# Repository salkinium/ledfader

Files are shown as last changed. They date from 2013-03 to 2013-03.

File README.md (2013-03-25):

Standalone driver for 32 LEDs
=============================

This board should drive 32 LEDs using 12bit resolution at a ~2kHz frequency
using two TLC5940s controlled by a ATmega328.
There is one button and a vibration sensor, to changes modes and save power (both optional).
The serial can be accessed (so Arduino support should be possible).

The software is written using the [XPCC library][xpcc], for its TLC5940 driver,
gamma correction and workflow classes.

Organisation
------------

This repository is organized as follows:

-	The *hardware* folder contains the EAGLE schematics and layouts of the
	electronic assembly, with parts list and datasheets.
- 	The *software* folder contains the software for the microcontroller.

[xpcc]: http://xpcc.kreatives-chaos.com

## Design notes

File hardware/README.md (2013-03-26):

LED driver hardware
===================

The ATmega328P can fade 32 LEDs using two TLC5940 12bit LED drivers.

Programmer
----------

The ATmega is programmed using the standard ISP interface, however to save space,
a smaller footprint is used.
On standard PCBs with 1.6mm thickness, the board fits exacly between to RM 2.00 pins,
so I just use a 2x3 RM 2.00 pin header to attach my programmer to it from the side.
This takes up a *lot* less space and the connection is secure enough.

Parts List and Description
--------------------------

### Battery charger

Using [Sparkfuns USB Lipo charger](
https://www.sparkfun.com/products/10401).

### Battery

This circuit can be powered by a standard 3.7V LiPo/LiIon rechargeable battery **without** voltage regulator.

### Microcontroller

A ATmega328P in a 32-pin TQFP package is used.

### Resonator

Small footprint, reasonable frequency stability of ±0.5% at 8MHz: CSTCE 8,00.

Some background on the maximum possible frequency:
The 3.7V LiPo battery voltage can be anywhere between 3V to 4.2V.

The ATmega328P is rated at 10Mhz @ 2.7V and 20Mhz @ 4.5V.
For 3V the maximum frequency is already above 10MHz, so we're fine.  

The lowest voltage for 8MHz is:  
(8MHz - 4MHz) * (2.7 - 1.8)V / (10 - 4)MHz + 1.8V = 2.4V

But the TLC5940 requires 3V minimum voltage, so never mind.

### Tactile Switch

A light touch switch from Panasonic is used:  
EVQPS with J-bend terminals: EVQPSG02K without Boss

### Vibration sensor

MVS 0608.02 is used.  
It's not widely available so you can leave it out.

### Other parts

Some 0603 and 0805 resistors and capacitors are used.

A RM 2.00 mm In-System Programming socket is used.

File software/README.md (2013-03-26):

LED drivers software
====================

The software is an example which manages all the LEDs on my bike helmet.
There is also some more advances stuff in there like sleep modes, which I use to minimize power use when the helmet is not in use.

You can/should adapt the firmware to your needs.
If you do not want to use XPCC, you should also be able to flash an Arduino bootloader on there (fingers crossed).

Firmware
--------

The sources are compiled using the [XPCC library][xpcc], which is used for
GPIO, TLC5940 Drivers, Processing, Build System and Serial Debugging.  
Enter the `source` directory

	$ cd /path/to/ledfader/software/source

To compile, execute:

	$ scons

The fuses are set at 0xad (low), 0xd9 (high), 0x07 (extended).  
To set the fuses on the microcontroller, execute:

	$ scons fuse

You can also set the fuses manually using this command:

	$ avrdude -p atmega328p -c avrispmkii -P usb -u \
	-U lfuse:w:0xad:m -U hfuse:w:0xd9:m -U efuse:w:0x07:m

To flash the binary onto the microcontroller, execute:

	$ scons program

Installing XPCC
---------------

XPCC is provided as a git submodule, to use it run this in the root `ledfader/`
directory:

	$ git submodule init
	$ git submodule update

To install the XPCC build system on OS X (tested on Lion/Mountain Lion):

1.	Install [Homebrew][]:  
	`$ ruby -e "$(curl -fsSL https://raw.github.com/mxcl/homebrew/go)"`
2.	Install some dependencies (requires Python 2.x):  
	`$ brew install scons python`  
	`$ pip install lxml jinja2`
3.	Install the latest precompiled version of [avr-gcc from ObDev][obdev].

To install the XPCC build system on Linux (tested on Ubuntu 12.04):

	$ sudo apt-get update
	$ sudo apt-get install python scons python-jinja2 python-lxml \
	gcc-avr binutils-avr avr-libc avrdude

More information on installing the XPCC build system can be [found here][xpcc-install].

[xpcc]: http://xpcc.kreatives-chaos.com/
[homebrew]: http://mxcl.github.com/homebrew/
[obdev]: http://www.obdev.at/products/crosspack/download.html
[xpcc-install]: http://xpcc.kreatives-chaos.com/install.html

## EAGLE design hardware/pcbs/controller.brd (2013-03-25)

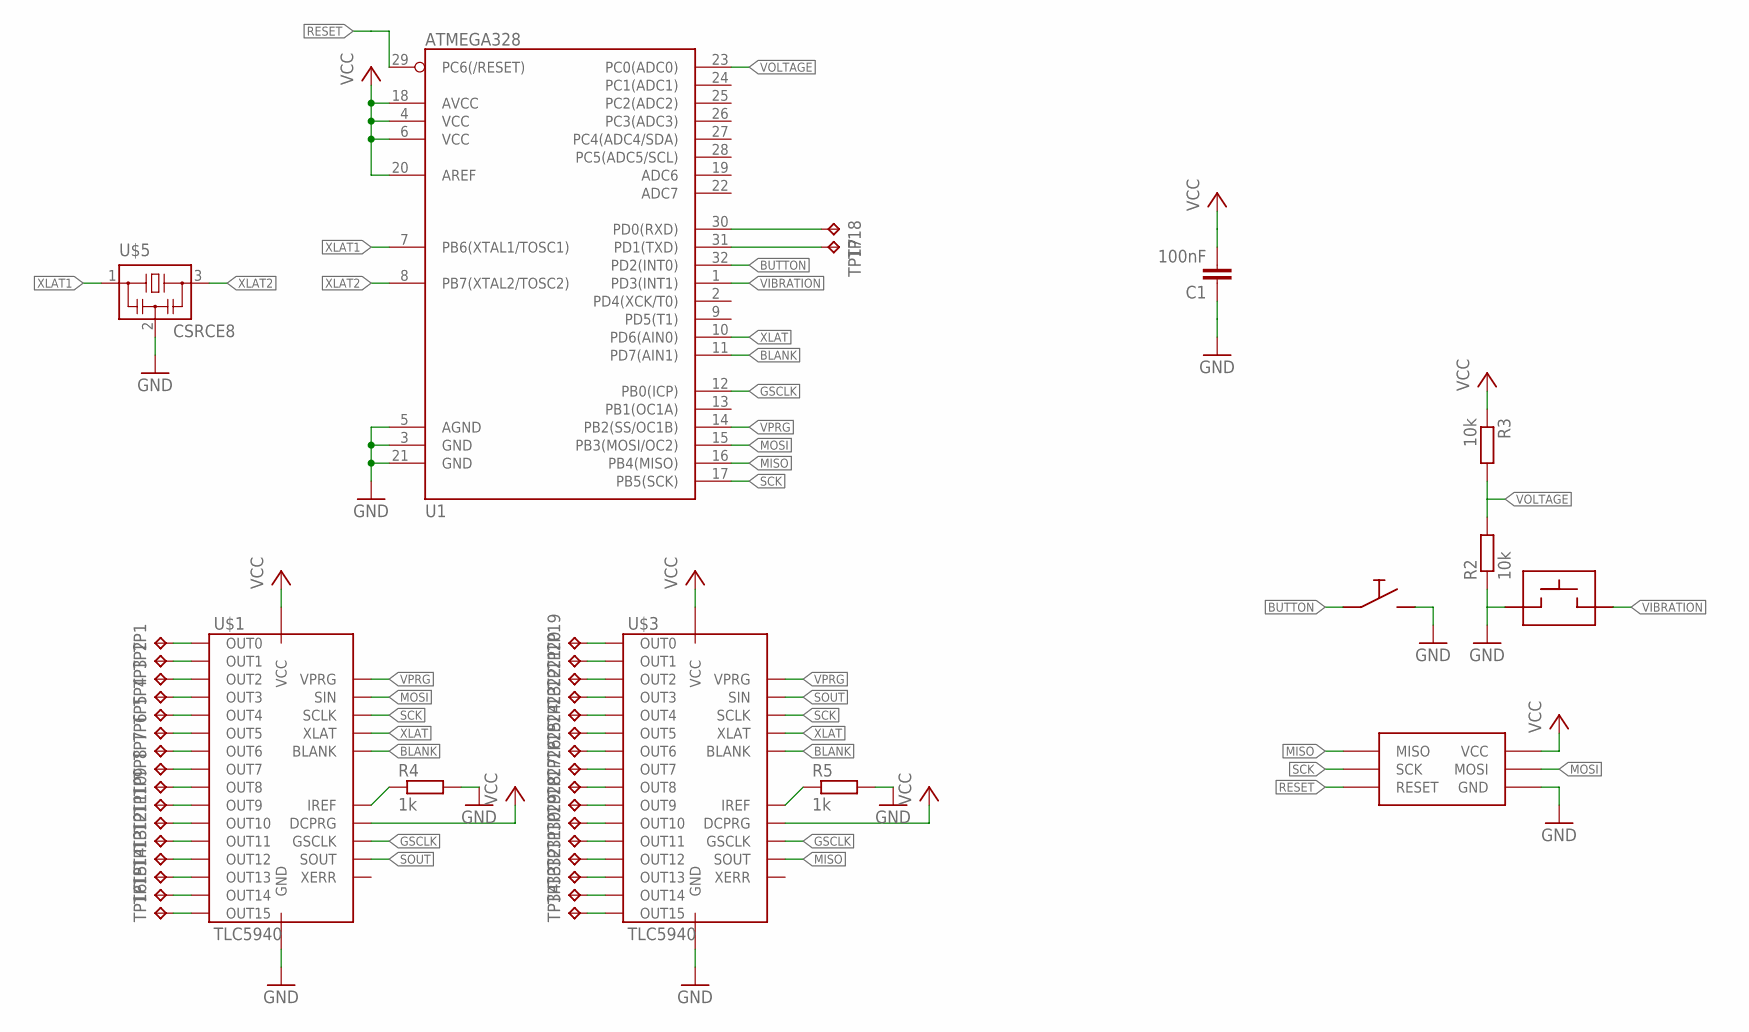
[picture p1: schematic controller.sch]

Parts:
C1: 100nF; C0603
R2, R3: 10k; R0603
R4, R5: 1k; R0603
TP1, TP2, TP3, TP4, TP5, TP6, TP7, TP8, TP9, TP10, TP11, TP12, TP13, TP14, TP15, TP16, TP17, TP18, TP19, TP20, TP21, TP22, TP23, TP24, TP25, TP26, TP27, TP28, TP29, TP30, TP31, TP32, TP33, TP34: TPTP15SQ; TP15SQ
U1: ATMEGA328; TQFP32-08
U$1, U$3: TLC5940; PWP_28PIN
U$2: ISP_SPECIALS; ISP_RM2_00_STRAIGHT
U$4: MOTION_SENSOR; MOTION
U$5: CSRCE8; CSTCE_G
U$6: SWITCH; EVQPSG02K

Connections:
BLANK: U1.11 (PD7(AIN1)), U$1.P2 (BLANK), U$3.P2 (BLANK)
BUTTON: U1.32 (PD2(INT0)), U$6.A, U$6.A@2
GND: C1.1, R2.1, R4.2, R5.2, U1.3 (GND), U1.5 (AGND), U1.21 (GND), U$1.P1 (GND), U$1.P29 (GND), U$2.VCC (GND), U$3.P1 (GND), U$3.P29 (GND), U$4.P$1 (IN), U$5.2, U$6.B, U$6.B@2
GSCLK: U1.12 (PB0(ICP)), U$1.P25 (GSCLK), U$3.P25 (GSCLK)
MISO: U1.16 (PB4(MISO)), U$2.RESET (MISO), U$3.P24 (SOUT)
MOSI: U1.15 (PB3(MOSI/OC2)), U$1.P5 (SIN), U$2.MOSI
unnamed: TP1.TP, U$1.P7 (OUT0)
unnamed: TP2.TP, U$1.P8 (OUT1)
unnamed: TP3.TP, U$1.P9 (OUT2)
unnamed: TP4.TP, U$1.P10 (OUT3)
unnamed: TP5.TP, U$1.P11 (OUT4)
unnamed: TP6.TP, U$1.P12 (OUT5)
unnamed: R4.1, U$1.P27 (IREF)
unnamed: TP7.TP, U$1.P13 (OUT6)
unnamed: TP8.TP, U$1.P14 (OUT7)
unnamed: TP9.TP, U$1.P15 (OUT8)
unnamed: TP10.TP, U$1.P16 (OUT9)
unnamed: TP11.TP, U$1.P17 (OUT10)
unnamed: TP12.TP, U$1.P18 (OUT11)
unnamed: TP13.TP, U$1.P19 (OUT12)
unnamed: TP14.TP, U$1.P20 (OUT13)
unnamed: TP15.TP, U$1.P21 (OUT14)
unnamed: TP16.TP, U$1.P22 (OUT15)
unnamed: R5.1, U$3.P27 (IREF)
unnamed: TP19.TP, U$3.P7 (OUT0)
unnamed: TP20.TP, U$3.P8 (OUT1)
unnamed: TP21.TP, U$3.P9 (OUT2)
unnamed: TP22.TP, U$3.P10 (OUT3)
unnamed: TP23.TP, U$3.P11 (OUT4)
unnamed: TP24.TP, U$3.P12 (OUT5)
unnamed: TP25.TP, U$3.P13 (OUT6)
unnamed: TP26.TP, U$3.P14 (OUT7)
unnamed: TP27.TP, U$3.P15 (OUT8)
unnamed: TP28.TP, U$3.P16 (OUT9)
unnamed: TP29.TP, U$3.P17 (OUT10)
unnamed: TP30.TP, U$3.P18 (OUT11)
unnamed: TP31.TP, U$3.P19 (OUT12)
unnamed: TP32.TP, U$3.P20 (OUT13)
unnamed: TP33.TP, U$3.P21 (OUT14)
unnamed: TP34.TP, U$3.P22 (OUT15)
RESET: U1.29 (PC6(/RESET)), U$2.MISO (RESET)
RX: TP18.TP, U1.30 (PD0(RXD))
SCK: U1.17 (PB5(SCK)), U$1.P4 (SCLK), U$2.SCK, U$3.P4 (SCLK)
SOUT: U$1.P24 (SOUT), U$3.P5 (SIN)
TX: TP17.TP, U1.31 (PD1(TXD))
VCC: C1.2, R3.1, U1.4 (VCC), U1.6 (VCC), U1.18 (AVCC), U1.20 (AREF), U$1.P26 (DCPRG), U$1.P28 (VCC), U$2.GND (VCC), U$3.P26 (DCPRG), U$3.P28 (VCC)
VIBRATION: U1.1 (PD3(INT1)), U$4.P$2 (OUT)
VOLTAGE: R2.2, R3.2, U1.23 (PC0(ADC0))
VPRG: U1.14 (PB2(SS/OC1B)), U$1.P6 (VPRG), U$3.P6 (VPRG)
XLAT: U1.10 (PD6(AIN0)), U$1.P3 (XLAT), U$3.P3 (XLAT)
XLAT1: U1.7 (PB6(XTAL1/TOSC1)), U$5.1
XLAT2: U1.8 (PB7(XTAL2/TOSC2)), U$5.3

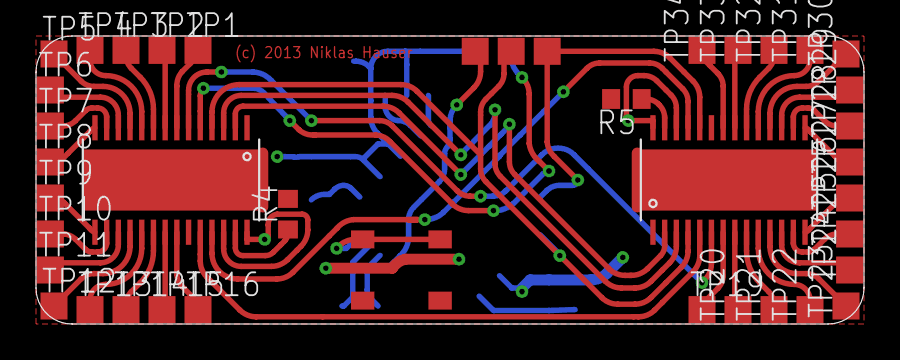
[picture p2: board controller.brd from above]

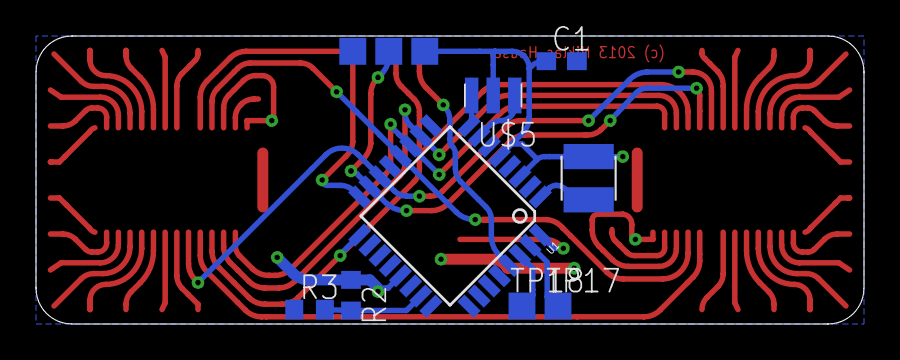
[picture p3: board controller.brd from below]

Board: 2 copper layers, 46.0 x 16.0 mm, 46 parts (8 on the bottom side), 52 nets.

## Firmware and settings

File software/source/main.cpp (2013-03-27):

/* coding: utf-8
 *
 */
#include <xpcc/architecture/platform.hpp>
#include <avr/sleep.h>
#include <avr/power.h>

#define UART_ENABLED 0

// IO #########################################################################
//
//                     +------------+
// (MOTION/INT1) PD3  1|o           |24  PC1
//               PD4  2|            |23  PC0 (ADC0/VOLTAGE)
//               GND  3|            |22  ADC7
//               VCC  4|            |21  GND
//               GND  5|            |20  AREF
//               VCC  6|            |19  ADC6
//       (XLAT1) PB6  7|            |18  AVCC
//       (XLAT2) PB7  8|            |17  PB5 (SCK)
//                     +------------+
//
//                     +------------+
//              PD5   9|           o|32  PD2 (BUTTON/INT0)
//       (XLAT) PD6  10|            |31  PD1 (TXD)
//      (BLANK) PD7  11|            |30  PD0 (RXD)
//      (GSCLK) PB0  12|            |29  PC6 (RESET)
//              PB1  13|            |28  PC5
//      (VPROG) PB2  14|            |27  PC4
//       (MOSI) PB3  15|            |26  PC3
//       (MISO) PB4  16|            |25  PC2
//                     +------------+


GPIO__INPUT(RXD, D, 0);
GPIO__OUTPUT(TXD, D, 1);

GPIO__INPUT(BUTTON, D, 2);
GPIO__INPUT(MOTION, D, 3);

GPIO__OUTPUT(VPROG, B, 2);
GPIO__OUTPUT(XLAT, D, 6);
GPIO__OUTPUT(BLANK, D, 7);
GPIO__OUTPUT(GSCLK, B, 0);

GPIO__INPUT(VOLTAGE, C, 0);

GPIO__INPUT(RESET, C, 6);
GPIO__OUTPUT(SCK, B, 5);
GPIO__OUTPUT(MOSI, B, 3);
GPIO__INPUT(MISO, B, 4);


// LED FADER ##################################################################
#include <xpcc/driver/ui/led.hpp>

typedef xpcc::atmega::SpiMaster LedSpi;
typedef xpcc::TLC594X< 32, LedSpi, XLAT, VPROG > controller;

// 10 white LEDs in the front
uint8_t whiteChannels[10] = {15,14,13,12,11,31,30,29,28,27};
xpcc::led::TLC594XMultipleLed< controller > white(whiteChannels, 10);

// six red LEDs in the back, four are constant
uint8_t redChannels[4] = {4,5,9,7};
xpcc::led::TLC594XMultipleLed< controller > red(redChannels, 4);

// two are pulsing
uint8_t redPulsingChannels[2] = {10,8};
xpcc::led::TLC594XMultipleLed< controller > redPulsingLed(redPulsingChannels, 2);
xpcc::led::Pulse redPulsing(&redPulsingLed, 1458);

// two position lights
uint8_t positionChannels[2] = {0,3};
xpcc::led::TLC594XMultipleLed< controller > position(positionChannels, 2);

// two beacon lights
xpcc::led::TLC594XLed< controller > beaconLed(6);
xpcc::led::Indicator beacon(&beaconLed, 2467, 0.28f, 130, 200);

// two strobe lights
uint8_t strobeChannels[2] = {1,2};
xpcc::led::TLC594XMultipleLed< controller > strobeLed(strobeChannels, 2);
xpcc::led::DoubleIndicator strobe(&strobeLed, 1825, 0.06f, 0.075f, 0.05f, 0, 20);

// blue stripes
uint8_t blueChannels[7] = {20,21,22,23,24,25,26};
xpcc::led::TLC594XMultipleLed< controller > blue(blueChannels, 7);

// io light
xpcc::led::TLC594XLed< controller > io(16);

// UART #######################################################################
#if UART_ENABLED
typedef xpcc::atmega::BufferedUart0 Uart;
Uart uart(38400);

#	include <xpcc/io/iodevice_wrapper.hpp>
#	include <xpcc/io/iostream.hpp>
xpcc::IODeviceWrapper<Uart> device(uart);
xpcc::IOStream stream(device);
#	define UART_STREAM(x) stream << x << xpcc::endl
#	define UART(x) uart.write(x)
#else
#	define UART_STREAM(x)
#	define UART(x)
#endif


// TIMEOUTS ###################################################################
#include <xpcc/workflow.hpp>
const uint16_t fadeTime = 5000;
xpcc::Timeout<> fadeOutTimer(fadeTime);
xpcc::Timeout<> fadeInTimer(fadeTime);

bool halfBrightness = true;
const uint8_t lowBrightness = 2;
const uint8_t highBrightness = 16;

const uint16_t motionTimeout = 10000;
xpcc::Timeout<> motionTimer(motionTimeout);
bool inMotion = true;
bool inMotionPrev = false;


const uint16_t buttonLongPressTime = 1000;
const uint16_t buttonShortPressTime = 50;
xpcc::Timeout<> buttonLongTimer(buttonLongPressTime);
xpcc::Timeout<> buttonShortTimer(buttonShortPressTime);

bool justWokeUp = false;
const uint16_t motionWakeTime = 2000;
const uint16_t motionWakeIntervalTime = 200;
xpcc::Timeout<> motionWakeTimer(motionWakeTime);
xpcc::Timeout<> motionWakeIntervalTimer(motionWakeIntervalTime);

enum
{
	BUTTON_NO_PRESS,
	BUTTON_DEPRESSED,
	BUTTON_SHORT_PRESS,
	BUTTON_LONG_PRESS,
} buttonState = BUTTON_SHORT_PRESS;
bool depressed;


// INTERRUPTS #################################################################
ISR(TIMER2_COMPA_vect)
{
	xpcc::Clock::increment();
	
	controller::writeChannels();
}

ISR(TIMER0_OVF_vect)
{
	BLANK::reset();
}

ISR(TIMER0_COMPB_vect)
{
	BLANK::set();
}

ISR(INT1_vect)
{
	// restart the motion timer with 10 seconds
	if (justWokeUp)
	{
		if (motionWakeTimer.isExpired() && !motionWakeIntervalTimer.isExpired())
		{
			justWokeUp = false;
			inMotion = true;
			motionTimer.restart(10000);
		}
		
		motionWakeIntervalTimer.restart(motionWakeIntervalTime);
		fadeOutTimer.restart(motionWakeIntervalTime);
	}
	else
	{
		inMotion = true;
		motionTimer.restart(10000);
	}
//	UART('m');
}

ISR(INT0_vect)
{
	// true button is "closed", false button is "open"
	depressed = !BUTTON::read();
	static bool depressedPrev = false;
	UART_STREAM("Button=" << depressed);
	
	if (depressed != depressedPrev)
	{
		depressedPrev = depressed;
		motionTimer.restart(10000);
		inMotion = true;
		
		if (depressed)
		{
			buttonShortTimer.restart(buttonShortPressTime);
			buttonLongTimer.restart(buttonLongPressTime);
			buttonState = BUTTON_DEPRESSED;
			io.on();
		}
		else
		{
			if (buttonState == BUTTON_DEPRESSED && !justWokeUp)
			{
				if (buttonLongTimer.isExpired())
				{
					buttonState = BUTTON_LONG_PRESS;
					UART_STREAM("Long Press");
				}
				else
				{
					if (buttonShortTimer.isExpired())
					{
						buttonState = BUTTON_SHORT_PRESS;
						UART_STREAM("Short Press");
					}
					else
					{
						buttonState = BUTTON_NO_PRESS;
						UART_STREAM("No Press");
					}
				}
			}
			
			io.off();
			EIMSK |= (1 << INT1);
			justWokeUp = false;
		}
	}
}


MAIN_FUNCTION // ##############################################################
{
	// Pull-up on Mode, Button and Motion pins
	BUTTON::setInput(xpcc::atmega::PULLUP);
	MOTION::setInput(xpcc::atmega::PULLUP);
	RESET::setInput(xpcc::atmega::PULLUP);
	TXD::setOutput();
	RXD::setInput();
	VOLTAGE::setInput();
	BLANK::setOutput(xpcc::gpio::LOW);
	SCK::setOutput();
	MOSI::setOutput();
	MISO::setInput();
	VPROG::setOutput(xpcc::gpio::LOW);
	XLAT::setOutput(xpcc::gpio::LOW);
	
	LedSpi::initialize(LedSpi::MODE_0, LedSpi::PRESCALER_2);
	set_sleep_mode(SLEEP_MODE_IDLE);
	
	// Set up interupts for the motion sensor and button
	// set external interrupt on any logical change for Button/Int0 and Motion/Int1
	EICRA = (1 << ISC00) | (1 << ISC10);
	// enable both external interrupts
	EIMSK = (1 << INT0) | (1 << INT1);
	
	// Fast PWM Mode, clear at Bottom
	TCCR0A = (1<<WGM00) | (1<<WGM01);
	// Grayscale counter going at 8000kHz/4096 = 1.953125kHz
	// this period should be slightly slower
	// 8000kHz / 64 / 65 = 1.92kHz
	TCCR0B = (1<<CS01) | (1<<CS00) | (1<<WGM02);
	OCR0A = 65;
	OCR0B = 64;
	// Enable Output Compare Match interrupt B
	TIMSK0 = (1<<OCIE0B) | (1<<TOIE0);
	
	// Enable 1ms interrupt
	// CTC Mode
	TCCR2A = (1<<WGM21);
	// 8000kHz / 64 / 125 = 1kHz = 1ms
	TCCR2B = (1<<CS22);
	OCR2A = 125;
	// Enable Overflow Interrupt
	TIMSK2 = (1<<OCIE2A);
	
	
	xpcc::atmega::enableInterrupts();
	UART_STREAM("\n\nRESTART\n");
	
	// 1.24V * 31.5 / (0.5kOhm) = 78.12mA
	// 64 / 78.12mA * 20mA = 16.41
	controller::initialize(0, highBrightness, true, false);
	
	
	while (1)
	{
		if (motionTimer.isExpired())
		{
			inMotion = false;
		}
		
		if (buttonState == BUTTON_LONG_PRESS)
		{
			buttonState = BUTTON_NO_PRESS;
			// disable motion sensor
			EIMSK &= ~(1 << INT1);
			inMotion = false;
		}
		
		if (inMotion != inMotionPrev)
		{
			inMotionPrev = inMotion;
			
			if (inMotion)
			{
				UART_STREAM("switching on");
				white.on(fadeTime);
				red.on(fadeTime);
				blue.on(fadeTime);
				position.on(fadeTime);
				
				fadeInTimer.restart(fadeTime);
			}
			else
			{
				UART_STREAM("switching off");
				white.off(fadeTime);
				red.off(fadeTime);
				blue.off(fadeTime);
				position.off(fadeTime);
				
				redPulsing.stop();
				beacon.stop();
				strobe.stop();
				
				fadeOutTimer.restart(fadeTime);
			}
		}
		
		if (buttonState == BUTTON_SHORT_PRESS)
		{
			buttonState = BUTTON_NO_PRESS;
			
			uint8_t brightness = halfBrightness ? lowBrightness : highBrightness;
			controller::setAllDotCorrection(brightness, false);
			if (!halfBrightness)
			{
				controller::setDotCorrection(6, 2*highBrightness);
				controller::setDotCorrection(11, 0x3f);
				controller::setDotCorrection(12, 0x3f);
				controller::setDotCorrection(13, 0x3f);
				controller::setDotCorrection(14, 0x3f);
				controller::setDotCorrection(15, 0x3f);
				controller::setDotCorrection(27, 0x3f);
				controller::setDotCorrection(28, 0x3f);
				controller::setDotCorrection(29, 0x3f);
				controller::setDotCorrection(30, 0x3f);
				controller::setDotCorrection(31, 0x3f);
				controller::setDotCorrection(4, 6);
				controller::setDotCorrection(5, 6);
				controller::setDotCorrection(7, 6);
				controller::setDotCorrection(9, 6);
			}
			controller::setDotCorrection(16, 1);
			{
				xpcc::atomic::Lock lock;
				controller::writeDotCorrection();
			}
			UART_STREAM("brightness=" << brightness);
			halfBrightness = !halfBrightness;
		}
		
		if (buttonState == BUTTON_DEPRESSED && buttonLongTimer.isExpired())
		{
			io.off();
		}
		
		if (inMotion && !beacon.isRunning() && fadeInTimer.isExpired())
		{
			redPulsing.start();
			beacon.start();
			strobe.start();
		}
		
		white.run();
		red.run();
		redPulsing.run();
		position.run();
		beacon.run();
		strobe.run();
		blue.run();
		io.run();
		
		if (!inMotion && fadeOutTimer.isExpired())
		{
			// turn off all LED driver outputs
			BLANK::set(xpcc::gpio::HIGH);
			// go to deep sleep
			set_sleep_mode(SLEEP_MODE_PWR_DOWN);
			justWokeUp = true;
			sleep_mode();
			// put mode back to idle
			set_sleep_mode(SLEEP_MODE_IDLE);
			
			UART_STREAM("wakeup");
			motionWakeTimer.restart(motionWakeTime);
		}
		else
		{
			sleep_mode();
		}
	}
}

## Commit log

2013-01-26 Add EAGLE libraries and layouts.
    [controller.brd, controller.sch]
2013-01-26 Add firmware source.
    [project.cfg]
2013-01-26 Add all LED controllers.
    [controller.brd]
2013-01-30 Add alternative, smaller layout of PCB. The PCB has less good thermal capabilities though.
    [controller2.brd, controller2.sch]
2013-02-25 Add xpcc as a submodule.
    [project.cfg]
2013-02-25 Add resistor and capacitor values to schematic.
    [controller2.brd, controller2.sch]
2013-02-25 Fix compilation error.
    [project.cfg]
2013-02-26 Add blank pin driver. New initialization sequence. Add new led driver classes.
    [controller2.brd, controller2.sch, project.cfg]
2013-03-05 Add VPROG pin to controller2.
    [controller2.brd, controller2.sch]
2013-03-05 Add a new controller design v3.
    [controller3.brd, controller3.sch]
2013-03-05 Disconnect thermal pad from GND. Add restrictions for easier soldering.
    [controller3.brd]
2013-03-25 Remove first two pcb iterations and replace with the third working one.
    [controller.brd, controller.sch, controller2.brd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]
2013-03-25 Add use of Button to code. Add sleep mode incl. power down for deep sleep.
2013-03-25 Add Led for Button interaction.
2013-03-26 Add ISP programmer footprint information.
2013-03-26 Add button debounce code. Dot Correction now set atomically. Added dot correction for all required leds.
    [main.cpp]
2013-03-26 Add delayed strobe, beacon and pulse start. Fix issue when coming out of deep sleep.
    [main.cpp]
2013-03-27 Add wake up filter to light up only after a certain time of continuos motion. Fix button state after wakeup.
    [main.cpp]

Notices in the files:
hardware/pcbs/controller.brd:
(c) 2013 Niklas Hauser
